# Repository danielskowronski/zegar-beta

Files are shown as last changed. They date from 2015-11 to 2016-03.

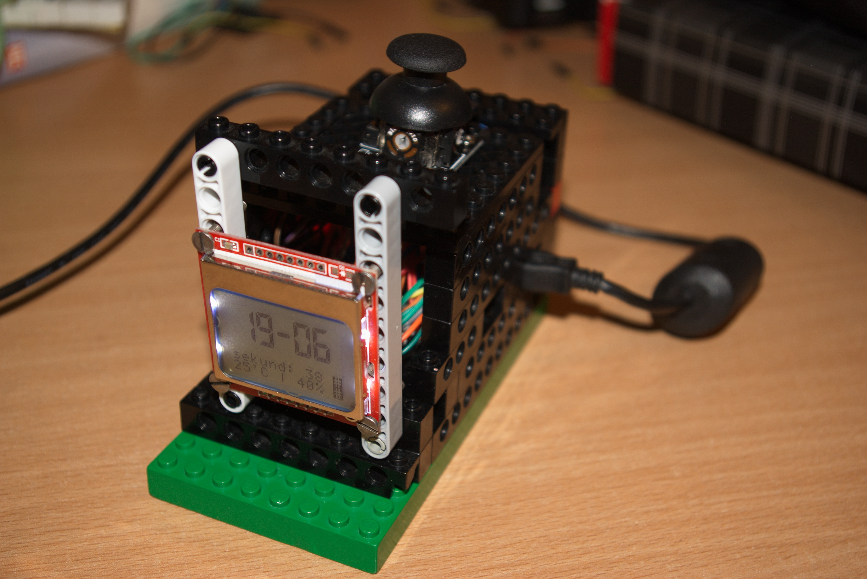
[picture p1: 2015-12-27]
demo/iter2/IMGP6967.jpg

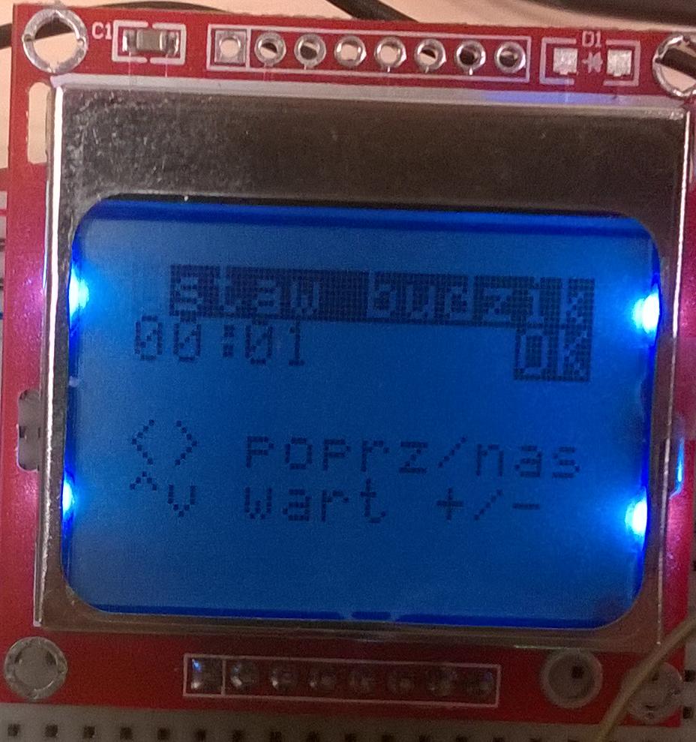
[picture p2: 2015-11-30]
demo/iter1/WP_20151130_18_45_15_Pro.jpg

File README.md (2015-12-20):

# zegar - beta
personal clock, version beta (not as in alpha-beta-rc-rtm-final but alpha-beta-gamma-... - concept version 2)

more details TBA

## casing
3d model to be printed on Prusa i3 printer

## electronics
arduino nano + rtc + thermometer + buzzer + joystick + nokia lcd

## code
I'm making it for myself so it may be weird for normal people (one of features is streaming temperature to PC via USB)

nice drawing on tiny screen and sound playing via interrupts are one of goals

## ideas - todo
- replace 80x40px LCD with 128x64px OLED screen (via I2C)
- snooze (+alarm) countdown if time remaining <=99min (2 digits) => func to compare timeObj
- more alarms => array of timeObj, somehow display settings (eg. via additional field on alarm adjusting page - alarm num, when changed - save tmp var like pos_setClock) => alarm on/off in settings not in main page => maybe alarm with configurable day of activation? => "1234567" with enabled in negative? => more objects!

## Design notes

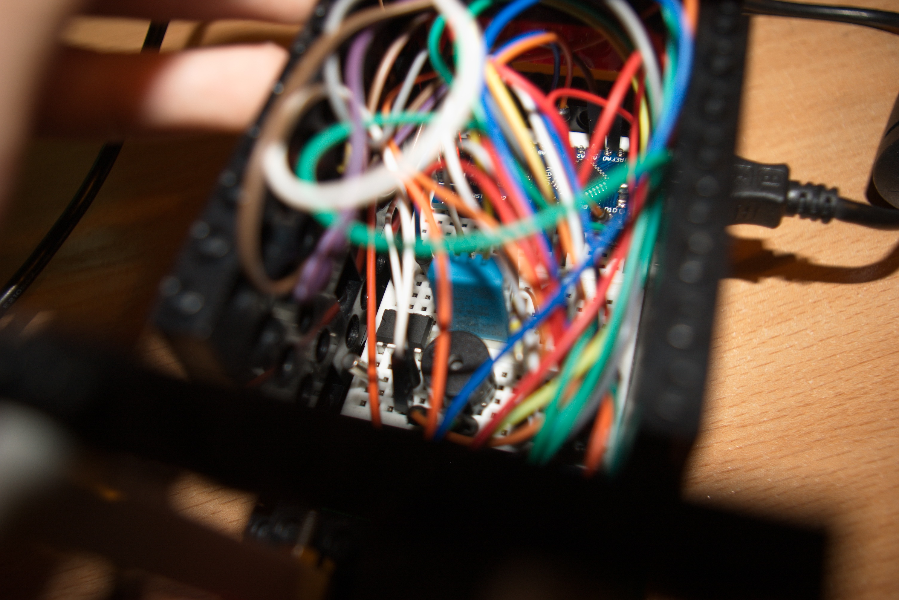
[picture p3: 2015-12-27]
demo/iter2/IMGP6969.jpg

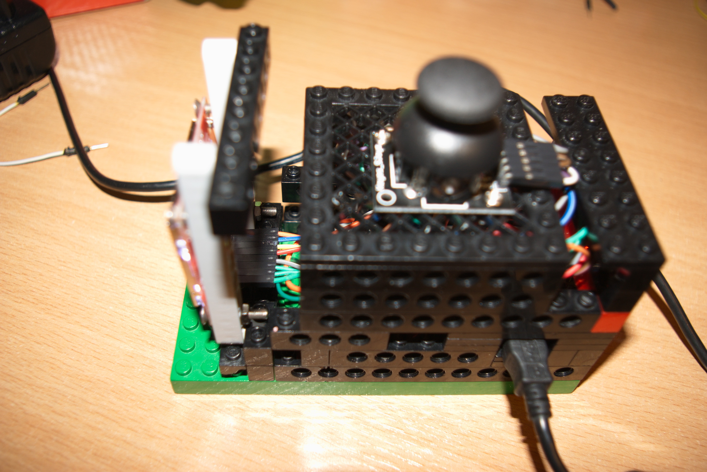
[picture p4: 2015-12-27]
demo/iter2/IMGP6968.jpg

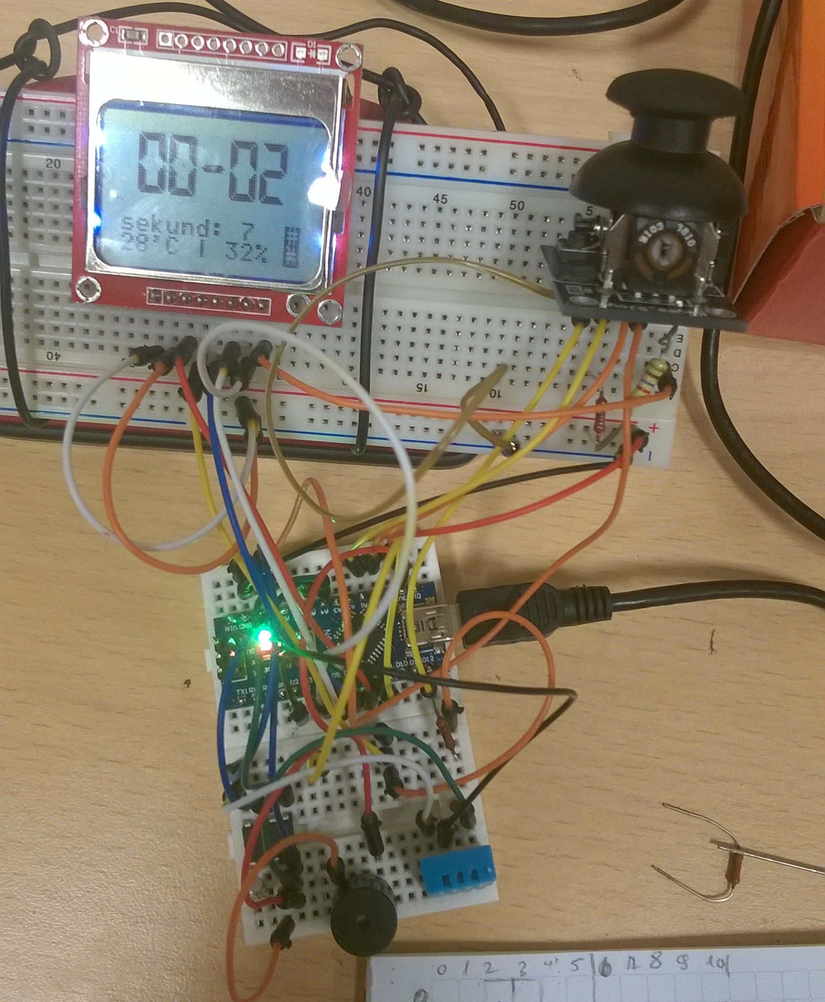
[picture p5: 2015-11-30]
demo/iter1/WP_20151130_18_44_44_Pro.jpg

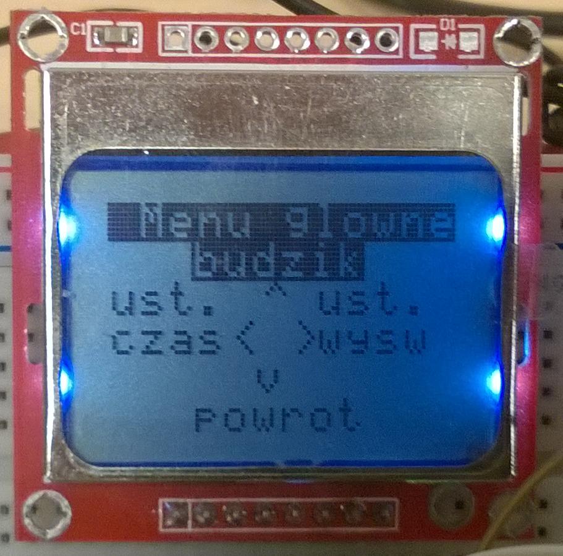
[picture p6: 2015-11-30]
demo/iter1/WP_20151130_18_45_07_Pro.jpg

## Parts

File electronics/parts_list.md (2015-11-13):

# Parts list
  - Arduino Nano v3
  - PCF8563p - RTC clock
  - 32.768Hz quartz + 100nF capacitors for RTC clock
  - 3V buzzer
  - DHT11 - temperature and humidity sensor
  - 2x 170 pole breadboard
  - Keyes_SJoys - PS3 joystick
  - PCD8544 - old Nokia LCD screen
  - 4.7K and 2.2K resistors
  - 9V battery as power source

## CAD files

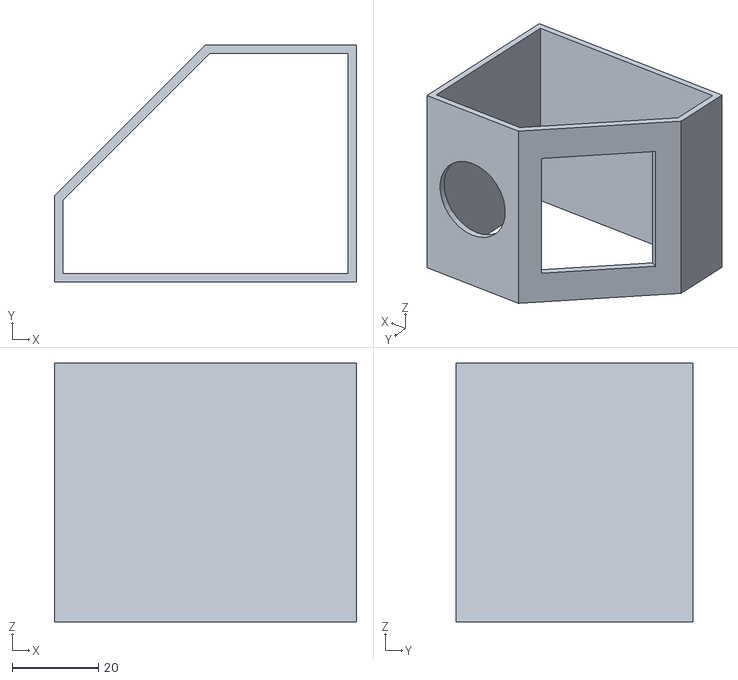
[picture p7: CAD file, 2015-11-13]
casing/zegar.stl
70.0 x 55.0 x 60.0

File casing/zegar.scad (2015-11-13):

difference(){
  difference(){
    //base
    linear_extrude(height = 60) 
      polygon( [
        [0,0],  [-70,0], [-70,20], [-35,55], [0,55], 
        [-2,2], [-68,2], [-68,19], [-34,53], [-2,53]
      ] ,[ [0,1,2,3,4],[5,6,7,8,9] ]  );

    //screen hole
    translate ([0,0,10])
      linear_extrude(height = 40) 
        polygon( [  
          [-62.5,24.5], [-64.5,25.5], [-40,50], [-38,48.5] 
        ] );
  };

  //joystick hole
  translate ([-35/2,50,30])
    rotate([0,-90,-90])
      linear_extrude(height = 10) 
        circle(d = 25);
}

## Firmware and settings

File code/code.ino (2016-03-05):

#include "data.h"
#include "config.h"
#include "display.h"
#include "ui.h"
#include "alarm.h"
#include "tools.h"

void setup(void) {
  Serial.begin(9600);  
  
  LcdInitialise();
  LcdClear();

  rtc.initClock();
  rtc.setDate(5, 3, 03, 21, 16);
  rtc.setTime(21, 25, 59);
  
  alarm = alarmTmp = timeObj(21,26);
  enableAlarm();

  dht.begin();

  pinMode(JOYSTICK_B, INPUT);  
  pinMode(BUZZ_PIN, OUTPUT);
  pinMode(LCD_BACKLIGHT, OUTPUT);

  setupAlamrInterrupt();
}

void loop(void){    
  readJoystick();
  parseAlarm();
  //transmitThm();//not usable now
  
  if (mode==0)
    displayClock();
  else if (mode==1) 
     showMenu(); 
  else if (mode==2) 
     setClock(false); //setAlarm
  else if (mode==3) 
     setClock(true); //setClock
  else if (mode==4) 
     setDisplay(); 
  
  delay(125);
}

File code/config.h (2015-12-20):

#ifndef CONFIG_H
#define CONFIG_H

#define JOYSTICK_X 1
#define JOYSTICK_Y 0
#define JOYSTICK_B 12

#define LCD_BACKLIGHT 11

#define BUZZ_PIN 10

#define LCD_PIN_SCE   7
#define LCD_PIN_RESET 8 //13
#define LCD_PIN_DC    6
#define LCD_PIN_SDIN  5
#define LCD_PIN_SCLK  4
#define LCD_C     LOW
#define LCD_D     HIGH
#define LCD_X     84
#define LCD_Y     48

#include <Rtc_Pcf8563.h>
extern Rtc_Pcf8563 rtc;

#include <DHT.h>
#define DHTPIN 2 
#define DHTTYPE DHT11
extern DHT dht;

#define SNOOZE_TIME 9

#endif

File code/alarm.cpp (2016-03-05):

#include "alarm.h"
#include "config.h"
#include "display.h" //jasnosc_val

timeObj::timeObj(int h, int m){ this->h=h; this->m=m; }
bool timeObj::isEqual(int h, int m){ return this->h==h&&this->m==m; }
void timeObj::addMinutes(int n){
  m+=n;
  while (m>=60){
    m-=60;
    h++;
  }
  h%=24; //there was &= instead of %= - tiny typo that caused snooze (only func that uses addMinutes) not to work
}

extern bool budzik=false;
extern timeObj alarm=timeObj(), alarmTmp=timeObj();
extern bool alarmENABLED=false, alarmSNOOZE=false, alarmCOMPLETED=false, alarmACTIVE=false;
extern volatile bool alarmINT=false;

void enableAlarm() { alarmENABLED=true; alarmCOMPLETED=false; }
void disableAlarm() { alarmENABLED=false; alarmCOMPLETED=true; }
void completeAlarm() { alarmCOMPLETED=true; }

void parseAlarm(){
  if (alarmENABLED && alarmTmp.isEqual(rtc.getHour(),rtc.getMinute())){
    alarmINT=true;
    alarmACTIVE=true;
  }
  if (alarmINT/* || alarmSNOOZE*/){
    analogWrite(LCD_BACKLIGHT, 255);
    delay(25);
    analogWrite(LCD_BACKLIGHT, 20);
    delay(25);
  }
  else{
    analogWrite(LCD_BACKLIGHT, jasnosc_val*2);
    alarmACTIVE=false;
    alarmINT=false;
  }
}

extern volatile /*not unsigned - there is `=-125` !*/ long int tick=0, stepp=0, todo=powt[stepp];

ISR(TIMER1_COMPA_vect){  //8kHz
  if (alarmINT){
    if (todo>=0){
      if (tick<czasy[stepp][0]) { digitalWrite(BUZZ_PIN, LOW);} 
      else if (tick>=czasy[stepp][0]&&tick<czasy[stepp][0]+czasy[stepp][1]) {digitalWrite(BUZZ_PIN, HIGH);}
      else  { digitalWrite(BUZZ_PIN, LOW);tick=-125;/*will be zeroed in next line!*/ todo--;}    
      tick+=125;
    }
    else{
      stepp++; if (stepp>10) stepp=0;
      todo=powt[stepp];
    }
  }
  else{
    tick=0; stepp=0; todo=powt[stepp];
    digitalWrite(BUZZ_PIN, LOW);
  }
}

void setupAlamrInterrupt(){
  cli();
  TCCR1A = 0;
  TCCR1B = 0;
  TCNT1  = 0;
  OCR1A = 249;
  TCCR1B |= (1 << WGM12);
  TCCR1B |= (1 << CS21);
  TIMSK1 |= (1 << OCIE1A);
  sei();
}

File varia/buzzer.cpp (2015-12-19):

#include <Wire.h>
#define BUZZ_PIN 10
void setup() {
  pinMode(BUZZ_PIN, OUTPUT);
}

//you can use it to play piano eg. 
/* String wlazlKotekNaPlotek[] = { "G","E","E","F","D","D","C","E","G","C","E","G","G","E","E","F","D","D","C","E","C","C","E","C","G","E","E","F","D","D","C","E","G","C","E","G","G","E","E","F","D","D","C","E","C","C","E" };
for (int i=0;i<47;i++) playNote(wlazlKotekNaPlotek[i]); */
void playNote(String note, int octave=6, int time=500){
  String notes[] = {
    "C",    "C#",     "D",    "D#",    "E",    "F",   "F#",    "G",   "G#",    "A",   "A#",    "H",
  };
  int sounds[][12] = {
    33,   35,    37,    39,   41,   44,   47,   49,   52,   55,   59,   62,
    65,   69,    73,    78,   82,   87,   93,   98,  104,  110,  117,  123,
    131,  139,  147,   156,  165,  175,  186,  196,  208,  220,  234,  247,
    262,  278,  294,   312,  330,  349,  371,  392,  416,  440,  467,  494,
    523,  555,  587,   619,  659,  698,  741,  784,  832,  880,  934,  988,
    1047, 1111, 1175, 1247, 1319, 1397, 1483, 1568, 1664, 1760, 1868, 1976,
    2093, 2221, 2349, 2493, 2637, 2794, 2965, 3136, 3328, 3520, 3736, 3951,
  };

  int d=0;
  for (int i=0;i<12;i++){if (notes[i]==note) {d=i; break;} }
  tone(BUZZ_PIN, sounds[octave-1][d]);
  delay(time);
  noTone(BUZZ_PIN);    
}

// somehow emulates Polish CEMI MC1203/MC1206 embedded alarm clock mellody which was very irritating and could wake the dead ;)
// original recording is in /varia/mc1203_budzik.mp3
void mc1203(){
  for (int n=1;n<=11;n++){
    switch (n){
      case 1:
      case 5:
        for (int i=0;i<409;i++) { digitalWrite(BUZZ_PIN, LOW); delayMicroseconds(480); digitalWrite(BUZZ_PIN, HIGH); delayMicroseconds(750); digitalWrite(BUZZ_PIN, LOW); }
        break;
      case 2:
      case 6:
        for (int i=0;i<187;i++) { digitalWrite(BUZZ_PIN, LOW); delayMicroseconds(1210); digitalWrite(BUZZ_PIN, HIGH); delayMicroseconds(1470); digitalWrite(BUZZ_PIN, LOW); }
        break;
      case 3:
      case 7:
        //for (int i=0;i<187;i++) { digitalWrite(BUZZ_PIN, LOW); delayMicroseconds(500); digitalWrite(BUZZ_PIN, HIGH); delayMicroseconds(2170); digitalWrite(BUZZ_PIN, LOW); }
        for (int i=0;i<185;i++) { digitalWrite(BUZZ_PIN, LOW); delayMicroseconds(500); digitalWrite(BUZZ_PIN, HIGH); delayMicroseconds(2220); digitalWrite(BUZZ_PIN, LOW); }
        break;
      case 4:
      case 11:
        delay(500);
        break;
      case 8:
        for (int i=0;i<1064;i++) { digitalWrite(BUZZ_PIN, LOW); delayMicroseconds(230); digitalWrite(BUZZ_PIN, HIGH); delayMicroseconds(240); digitalWrite(BUZZ_PIN, LOW); }
        break;
      case 9:
        for (int i=0;i<515;i++) { digitalWrite(BUZZ_PIN, LOW); delayMicroseconds(250); digitalWrite(BUZZ_PIN, HIGH); delayMicroseconds(720); digitalWrite(BUZZ_PIN, LOW); }
        break;
      case 10:
        for (int i=0;i<187;i++) { digitalWrite(BUZZ_PIN, LOW); delayMicroseconds(1020); digitalWrite(BUZZ_PIN, HIGH); delayMicroseconds(1690); digitalWrite(BUZZ_PIN, LOW); }
        break;
    }
  }
}

void loop() {
  mc1203();
}

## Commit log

2015-11-13 initial commit; parts list; casing basic model
    [zegar.scad, zegar.stl]
2015-11-30 first iter - elements connected + basic code; menu navigation, clock set/display, alarm set, temperature show works
2015-12-18 memory and display optimizations
    1) huge static font arrays moved to PROGMEM (extra 1kB of SRAM!, there
    was just approx. 300B and on some operations system was unstable)
    2) removed full screen redraw every 100ms tick - now basics are drawn
    only when layout changes, only variable parts are redrawn - modechanged
    variable
    3) empty_line constant was created to unify line clearing
    4) LCD unused reset pin moved to 8 because 13 is also connected to
    bright led on arduino board
    5) LCD Vop fixed
2015-12-19 mc1203 alarm mellody and other buzzer experiments
    to be implemented in main code as alarm sound
    [buzzer.cpp]
2015-12-20 alarm sound via inetrrupts, lcd backlight config
    1) alarm sound (MC1203 - check varia/buzzer.cpp) done via internal AVR
    interrupts
    2) blink lcd backlight on alarm
    3) lcd backlight configuration in menu
    4) tweak main loop delay for better <> prev/next field navigation in
    menu
2015-12-20 code reorganization
    huge main.cpp divided into smaller files,
    main.cpp moved to main.ino to be easier imported into arduino studio
    all pins are now described by const
2016-03-05 snooze fixed (typo destroyed func), display improvements
    [alarm.cpp, code.ino, config.h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]
2016-03-05 post deployment after test fixes
    [config.h, ui.cpp]
